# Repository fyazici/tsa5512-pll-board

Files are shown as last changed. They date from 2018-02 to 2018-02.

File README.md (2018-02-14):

# tsa5512-pll-board
PCB for VCO combined with the TV/VCR Tuner controller TSA5512T

VCO is implemented with a simple varactor controlled Colpitts oscillator. 
Capacitor/Inductor values should be adjusted according to the desired operating frequency range. Current component values are chosen to oscillate in FM band.
TSA5512 is a cheap Philips PLL IC mainly made for TV tuner applications. DIY-famous UV916 tuner also contains this chip (like many other tuners).
PLL is configured over I2C, which can easily be achieved with an Arduino board. Programming details can be found in the datasheet (http://pira.cz/pdf/TSA5512.pdf)

Some components are through-hole, because I've had a bunch of them at hand. SMD resistor/capacitors are spread all over the board and they can easily be found on any scrap electronic equipment with a sufficient size.
For higher frequency requirements (UHF band, ~300MHz) original tuner designs can be taken as a reference. BFR92 transistor will be more appropriate for the oscillator and special care should be taken in order to encapsulate the signal nets (t. lines and keepout regions mainly).

3D board view of the top-side:
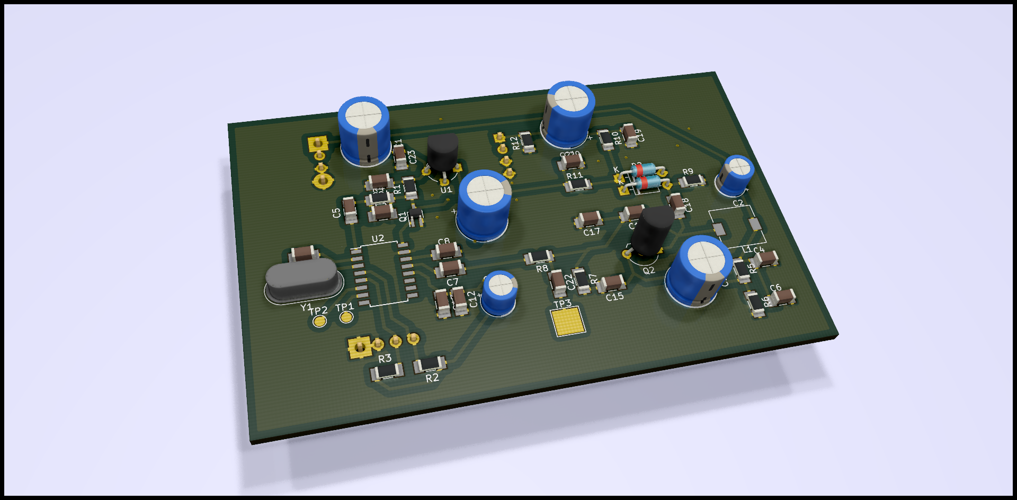
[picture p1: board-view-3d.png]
3D board view


Note that the gerber outputs are not up-to-date (belongs to an erroneus version). I've laser-printed the board so I did not care about special requirements of any PCB manufacturer. A revisit of layout is required to meet manufacturer demands (some I know of are: OSH Park, Seeedstudio)

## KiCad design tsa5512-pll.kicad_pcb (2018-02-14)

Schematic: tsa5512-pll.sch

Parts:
C1, C9, C14, C20: 10u; CP_Radial_D8.0mm_P3.80mm
C2, C10: 1u; CP_Radial_D5.0mm_P2.50mm
C3: 39n; C_1206_3216Metric_Pad1.24x1.80mm_HandSolder
C4, C12, C23: 4n7; C_1206_3216Metric_Pad1.24x1.80mm_HandSolder
C5: 180n; C_1206_3216Metric_Pad1.24x1.80mm_HandSolder
C6, C13, C24: 150p; C_1206_3216Metric_Pad1.24x1.80mm_HandSolder
C7, C8: 1n; C_1206_3216Metric_Pad1.24x1.80mm_HandSolder
C11: 27p; C_1206_3216Metric_Pad1.24x1.80mm_HandSolder
C15: 10n; C_1206_3216Metric_Pad1.24x1.80mm_HandSolder
C16, C17: 15p; C_1206_3216Metric_Pad1.24x1.80mm_HandSolder
C18: 330p; C_1206_3216Metric_Pad1.24x1.80mm_HandSolder
C19, C21: 47p; C_1206_3216Metric_Pad1.24x1.80mm_HandSolder
C22: 22p; C_1206_3216Metric_Pad1.24x1.80mm_HandSolder
D1, D2: BB221; D_DO-35_SOD27_P7.62mm_Horizontal
J1, J2, J3: Conn_01x04; PinHeader_1x04_P2.54mm_Vertical
L1: 100n; L_7.3x7.3_H3.5
Q1: BC848W; SOT-323_SC-70_Handsoldering
Q2: BF199; TO-92L_Inline_Wide
R1, R5, R6: 15k; R_1206_3216Metric_Pad1.24x1.80mm_HandSolder
R2, R3, R11: 10k; R_1206_3216Metric_Pad1.24x1.80mm_HandSolder
R4: 22k; R_1206_3216Metric_Pad1.24x1.80mm_HandSolder
R7: 270R; R_1206_3216Metric_Pad1.24x1.80mm_HandSolder
R8: 680R; R_1206_3216Metric_Pad1.24x1.80mm_HandSolder
R9, R10, R12: 4k7; R_1206_3216Metric_Pad1.24x1.80mm_HandSolder
TP1, TP2: Test_Point; TestPoint_Pad_D1.5mm
TP3: Test_Point; TestPoint_Pad_4.0x4.0mm
U1: L78L05_TO92; TO-92_Wide
U2: TSA5512T; SOIC-16W_5.3x10.2mm_P1.27mm
Y1: 4MHz; Crystal_HC49-4H_Vertical

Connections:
+5V: C9.1, C10.1, C12.1, C13.1, R2.1, R3.1, U1.1 (VO), U2.12
+12V: C1.1, C2.1, C4.1, C6.1, C23.1, C24.1, J1.1, J1.2, L1.1, R1.2, R5.1, U1.3 (VI)
/OSC_OUT: C7.1, R8.2
/SCL: J2.3, R3.2, U2.5
/SDA: J2.4, R2.2, U2.4
/VTUNE: C3.2, C21.1, Q1.3 (C), R1.1, R4.2, R11.1
GND: C1.2, C2.2, C4.2, C6.2, C8.2, C9.2, C10.2, C12.2, C13.2, C14.2, C15.2, C17.2, C19.2, C21.2, C23.2, C24.2, D2.2, J1.3, J1.4, J2.1, J2.2, J3.3, J3.4, Q1.2 (E), R6.2, R7.2, R9.2, R12.1, U1.2 (GND), U2.15
unnamed: C3.1, C5.2, R4.1
unnamed: C5.1, U2.1
unnamed: C7.2, U2.13
unnamed: C8.1, U2.14
unnamed: C11.1, U2.2
unnamed: C11.2, Y1.2
unnamed: C14.1, C15.1, Q2.3, R5.2, R6.1
unnamed: C16.1, C18.2, L1.2, Q2.1
unnamed: C16.2, C17.1, C22.1, Q2.2, R7.1, R8.1
unnamed: C18.1, D1.2, R9.1
unnamed: C19.1, C20.1, R10.1
unnamed: C20.2, J3.1, J3.2, R12.2
unnamed: C22.2, TP3.1
unnamed: D1.1, D2.1, R10.2, R11.2
unnamed: Q1.1 (B), U2.16
unnamed: TP1.1, U2.7
unnamed: TP2.1, U2.6
unnamed: U2.3, Y1.1

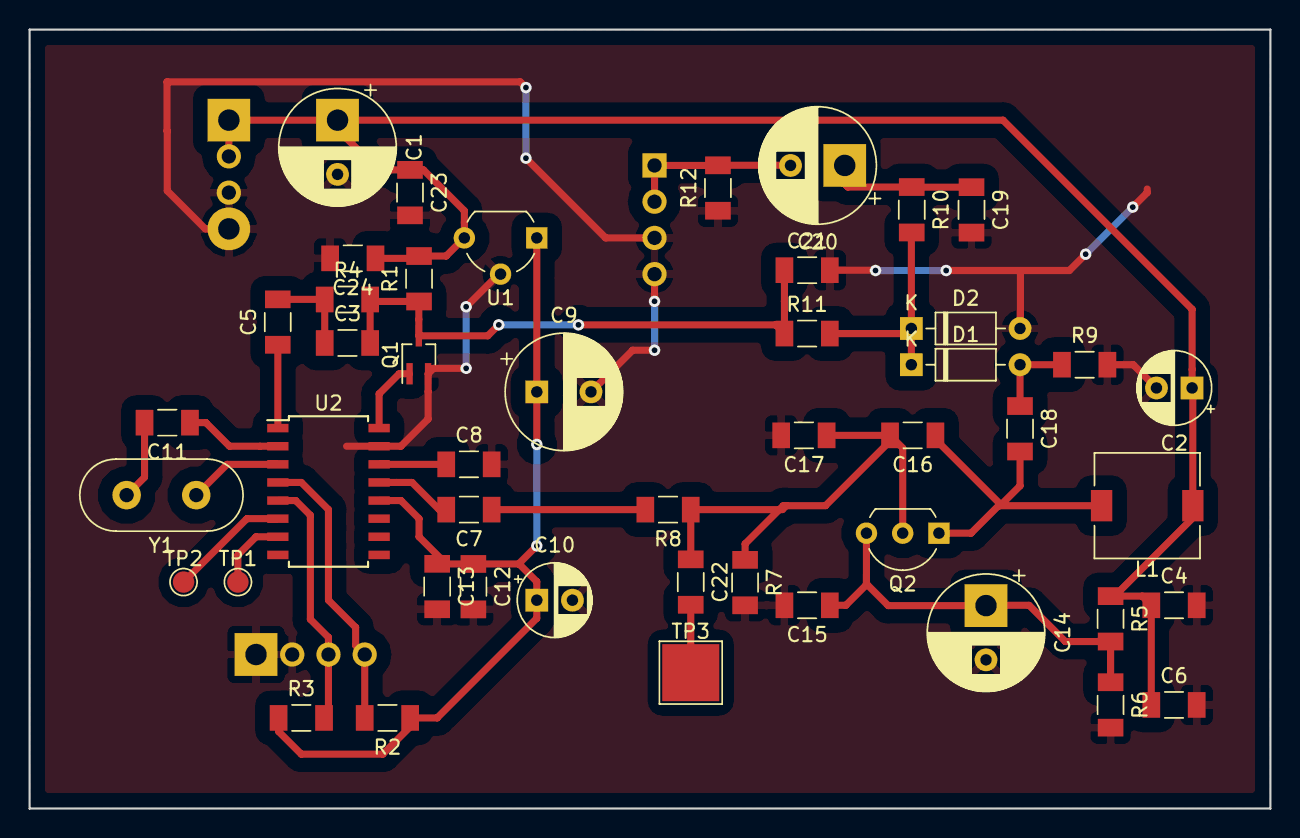
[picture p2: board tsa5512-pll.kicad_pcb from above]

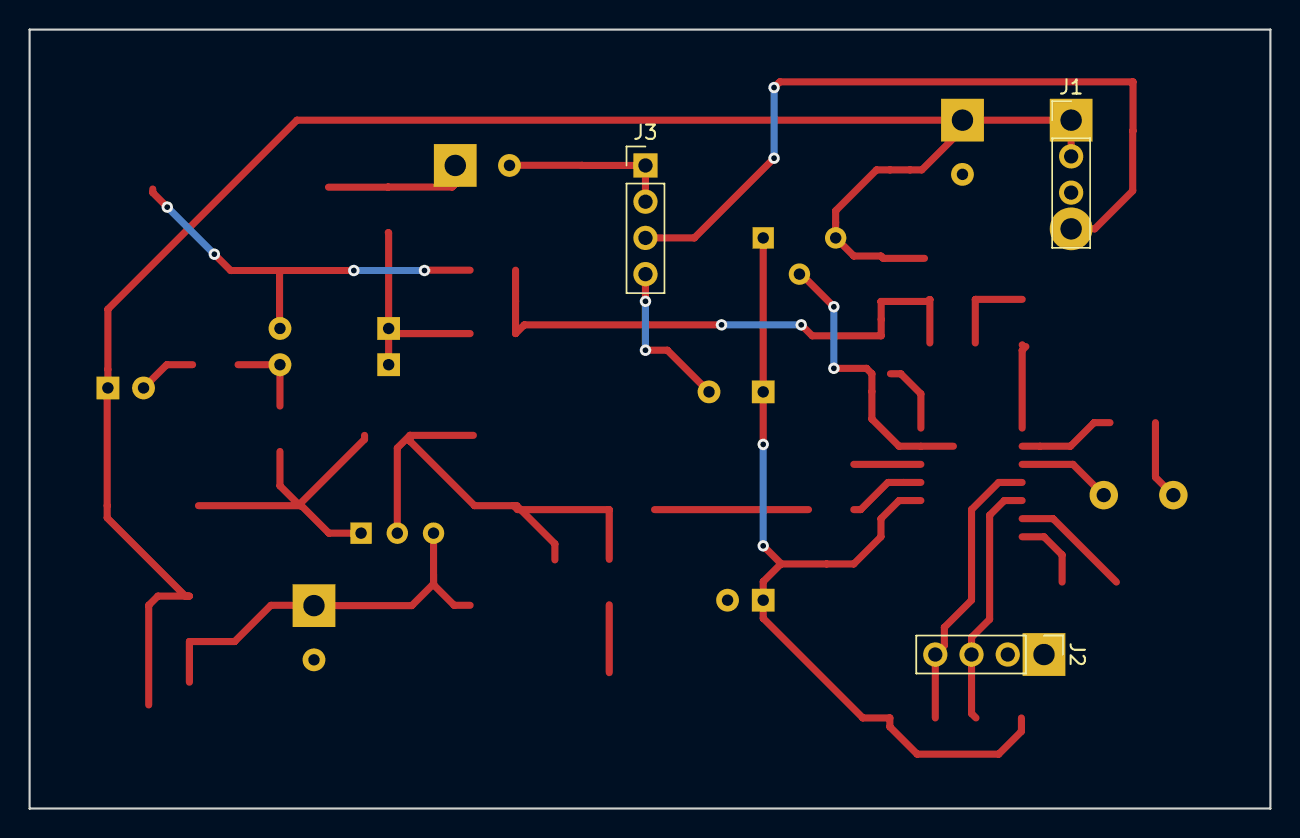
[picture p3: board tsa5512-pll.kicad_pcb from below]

Board: 2 copper layers, 87.0 x 54.6 mm, 50 parts (3 on the bottom side), 25 nets.
